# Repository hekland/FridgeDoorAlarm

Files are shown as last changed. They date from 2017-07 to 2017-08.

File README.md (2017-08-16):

# README #

### What is this repository for? ###

**Low-power circuit-break detector using the ATtiny85, to ensure that the fridge and freezer doors are closed**

* Version 1.0 (2017-07-30): Initial release
* Version 1.1 (2017-08-16): Tweaked door circuit sensing method to provide more stable readings

This program will, every eight seconds, check the two circuits 
to see whether they're open or closed. This is typically the fridge
and the freezer door. If the fridge door is open for more than three minutes
the piezo-buzzer will beep three times followed by four seconds pause, and continue until it's closed. 
For the freezer door, nine beeps will be produced.
In addition, an LED will blink briefly every 60 seconds to show it's alive.

The ATtiny85 is using a 1MHz internal clock, and will run for 3 years on 
a 220mAh CR2032 coin cell battery. If the LED is omitted, over 4 years runtime
is expected.

### How do I get set up? ###

**What you need**

* [ATtiny support for Arduino IDE](https://github.com/damellis/attiny)
* [Low-power Library for Arduino with ATtiny85-support](https://github.com/sej7278/LowPower)
* An Arduino Uno for programming the ATtiny85.
* Some hardware as described in the Fritzing file.

**How to program the ATtiny85**

* [Setup your Uno as programmer](http://highlowtech.org/?p=1706)
* [Burn bootloader on the ATtiny85 using the 1MHz internal clock, and install sketch](http://highlowtech.org/?p=1695)

### Contribution guidelines ###

### Who do I talk to? ###

Written by: Fredrik Hekland

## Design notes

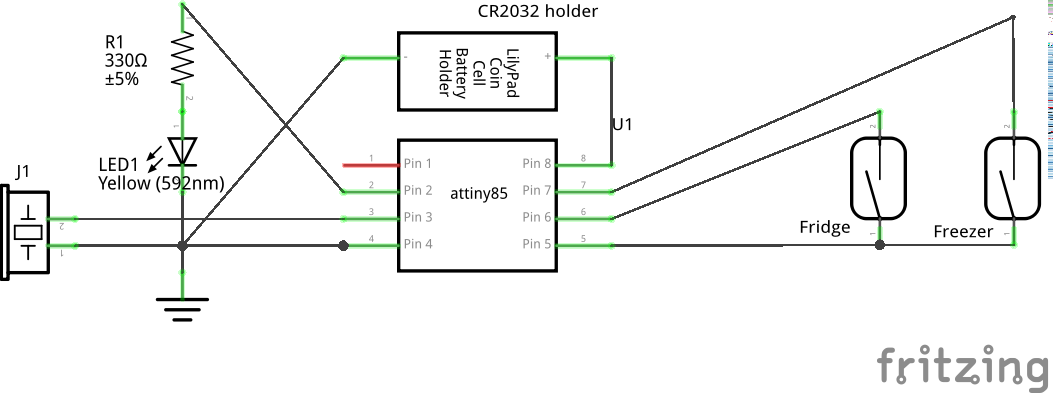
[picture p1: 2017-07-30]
hardware/open_fridge_door_alarm_schem.png

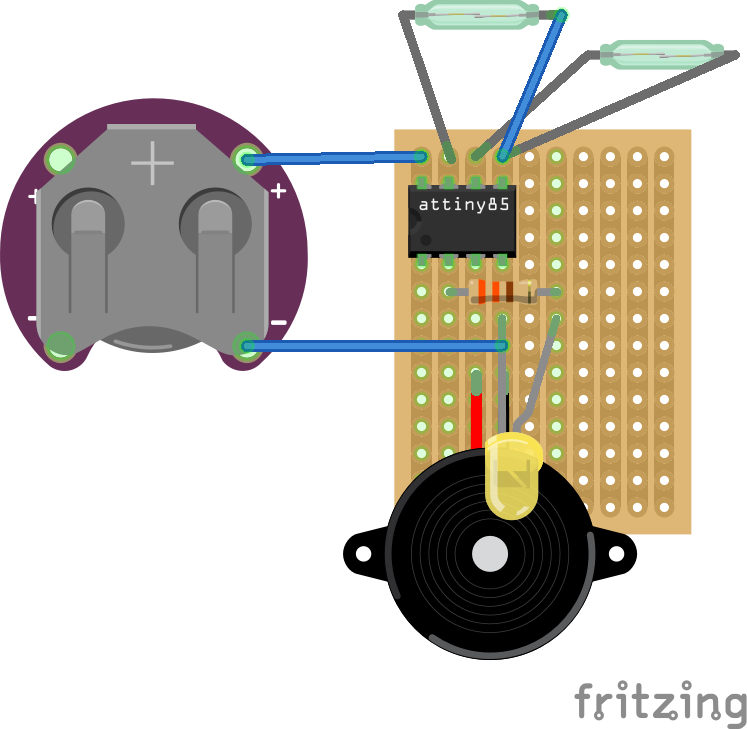
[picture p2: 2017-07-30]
hardware/open_fridge_door_alarm_bb.png

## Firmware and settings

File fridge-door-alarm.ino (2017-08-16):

/* Low-power dual circuit-break detector using the ATtiny85
* 
* This program will, every eight seconds, check the two circuits 
* to see whether they're open or closed. This is typically the fridge
* and the freezer door. If the fridge door is open for more than three minutes
* the piezo-buzzer will beep three times followed by four seconds pause and continue 
* until it's closed. For the freezer door, nine beeps will be produced.
* In addition, an LED will blink briefly every 60 seconds to show it's alive.
* The ATtiny85 is using a 1MHz internal clock.
* 
* The program uses approximately 5.8uA without the LED, and 7.8uA with the
* current configuration (red LED, 330ohm resistor, 15ms blink and 60s interval),
* and door circuit checking every 8 sec, running 350uA for 15ms for each circuit.
* With 7.8uA average current consumption, a CR2032 coin cell battery with 220mAh
* will give 3.2 years life. Without the LED, 4.3 years.
* 
* Low-power modes are attained using the LowPower library:
* https://github.com/sej7278/LowPower which is based on the 
* LowPower library from Rocket Scream Electronics(www.rocketscream.com)
* 
* Written by: Fredrik Hekland
* Date: 2017-07-26
* Last update: 2017-08-16
* 
* This code is licensed under Creative Commons Attribution-ShareAlike 3.0
* Unported License.
*/

#include <LowPower.h>

const uint8_t PIN_SWITCH_VCC    = 0;
const uint8_t PIN_FRIDGE_SENSE  = 1;
const uint8_t PIN_FREEZER_SENSE = 2;
const uint8_t PIN_LED           = 3;
const uint8_t PIN_BUZZER        = 4;

const uint16_t BUZZER_TIMEOUT_S = 176; // ~3min time-out before alarm sounds
const uint8_t LED_INTERVAL_S    = 60;  // Blink alive-LED once a minute

boolean isAlarmActive     = false;
uint16_t durationOpenDoor = 0;
uint8_t ageLEDblink       = LED_INTERVAL_S;

void setup() 
{
  pinMode(PIN_SWITCH_VCC, OUTPUT);
  digitalWrite(PIN_SWITCH_VCC, HIGH);

  pinMode(PIN_FRIDGE_SENSE, INPUT_PULLUP);
  pinMode(PIN_FREEZER_SENSE, INPUT_PULLUP);

  pinMode(PIN_LED, OUTPUT);
  digitalWrite(PIN_LED, LOW);

  pinMode(PIN_BUZZER, OUTPUT);
  digitalWrite(PIN_BUZZER, LOW);
  
  pinMode(5, INPUT_PULLUP); // power-save
}

void loop()
{
  boolean isFridgeOpen  = checkIsDoorOpen(PIN_FRIDGE_SENSE);
  boolean isFreezerOpen = checkIsDoorOpen(PIN_FREEZER_SENSE);
  if ( isFridgeOpen || isFreezerOpen )
  {
    if ( durationOpenDoor > BUZZER_TIMEOUT_S )
      isAlarmActive = true;
    if ( isAlarmActive )
    {
      uint8_t Nbeeps = (isFreezerOpen ? 9 : 3);
      for (uint8_t i = 0; i < Nbeeps; ++i)
      {
        togglePinHigh(SLEEP_120MS, PIN_BUZZER);
      }
    }
    LowPower.powerDown(SLEEP_4S, ADC_OFF, BOD_OFF);
    durationOpenDoor += 4;
    ageLEDblink += 4;
  }
  else // doors are closed
  {
    durationOpenDoor = 0;
    isAlarmActive = false;
    LowPower.powerDown(SLEEP_8S, ADC_OFF, BOD_OFF);
    ageLEDblink += 8;
  }
  
  if (ageLEDblink >= LED_INTERVAL_S)
  {
    togglePinHigh(SLEEP_15MS, PIN_LED);
    ageLEDblink = 0;
  }
}

/**
 * Toggle a pin high for a given period.
 * Used to blink the LED or sound the buzzer.
 * 
 * Must use idle mode since powerDown seems to provide
 * unstable/less pin current.
 * 
 * \param period The period to keep the pin high
 * \param pinNr The pin to toggle
 */
void togglePinHigh(period_t period, uint8_t pinNr)
{
  digitalWrite(pinNr, HIGH);
  LowPower.idle(period, ADC_OFF, TIMER1_OFF, TIMER0_OFF);
  digitalWrite(pinNr, LOW);
  LowPower.idle(period, ADC_OFF, TIMER1_OFF, TIMER0_OFF);
}

/**
 * Check whether a door has been opened, thus breaking
 * the circuit.
 * 
 * \param pin The input pin to check whether circuit has been broken
 */
uint8_t checkIsDoorOpen(uint8_t pin)
{
  digitalWrite(PIN_SWITCH_VCC, LOW); // run current through door circuit
  LowPower.idle(SLEEP_15MS, ADC_OFF, TIMER1_OFF, TIMER0_OFF); // give time to stabilize
  uint8_t val = digitalRead(pin); // high if open door, low if closed
  digitalWrite(PIN_SWITCH_VCC, HIGH); // shutoff current to save energy
  return val;
}

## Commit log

2017-07-30 Add source files
    [Battery_life_calculation.ods, open_fridge_door_alarm.fzz]
2017-08-16 For more stable readings, run current through the door circuits for a longer time.
    [Battery_life_calculation.ods]
